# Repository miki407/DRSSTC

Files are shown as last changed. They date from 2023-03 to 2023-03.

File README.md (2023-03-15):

# Welcome
> **WARNING:**
> This project has not been tested yet. I cant guarantee that any of the circuits, PCBs, 3d models work or are accurate.

>This project is incomplete. The README isn't finished yet.

## Overview

This project is a tesla coil, DRSSTC to be more exact. Tesla coils are devices capable of generating extreme voltages that can be lethal if not operated correctly. 
> **Warning:** This project deals with high voltages. Replicate at your own risk.
 
 It is designed with a full bridge inverter connected to a MMC as the primary tank capacitor. This full bridge uses 4 parallel IGBT pairs driven by a single GDT. This GDT connects to the control circuit. Using a MIDI interrupter this coil has the ability to play music.

## Physical Design

The coil is designed with a skeleton topload and a vertical breakout point located in the middle of the topload. The primary coil is a pancake with a ground ring that is meant to protect it from flashover from topload.
>Note: The grounding ring is shouldn't be closed loop like shown in the image. This would short circuit the induced current and cause large current draw and energy loss.

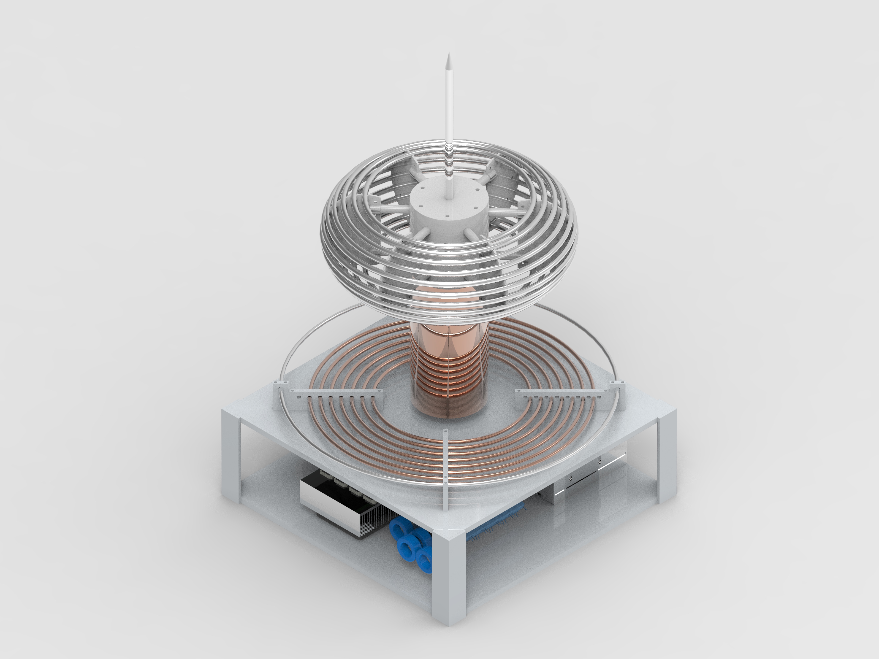
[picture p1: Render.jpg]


## Circuit
The circuit for the control circuit and inverter are inspired by the UD2.7c and EasyBridge made by [Loneoceans](https://www.loneoceans.com/labs/index.htm). These circuits have been modified to fit the needs of this project.
The interactive BOM of these boards are here:
[Inverter](https://htmlpreview.github.io/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)
[Control circuit](https://htmlpreview.github.io/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)

## Future additions

* Polyphonic MIDI interrupter
* Testing data
* Assembly guide
* Full BOM 

## Mistakes and Suggestions 
If I made any mistakes or if you want to suggest anything you can contact me on milosmilicevic575@gmail.com.

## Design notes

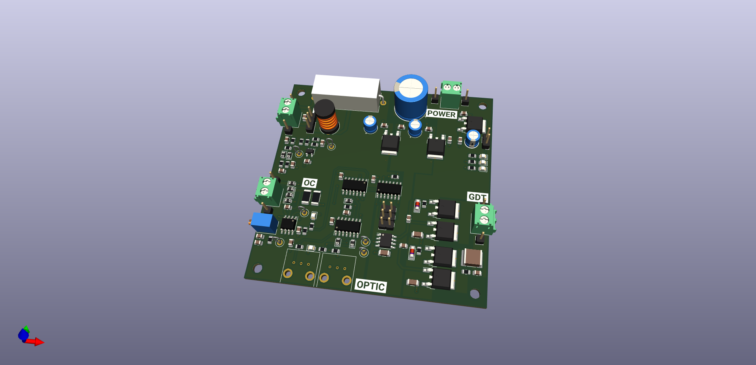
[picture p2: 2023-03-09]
DRSSTC controller.png

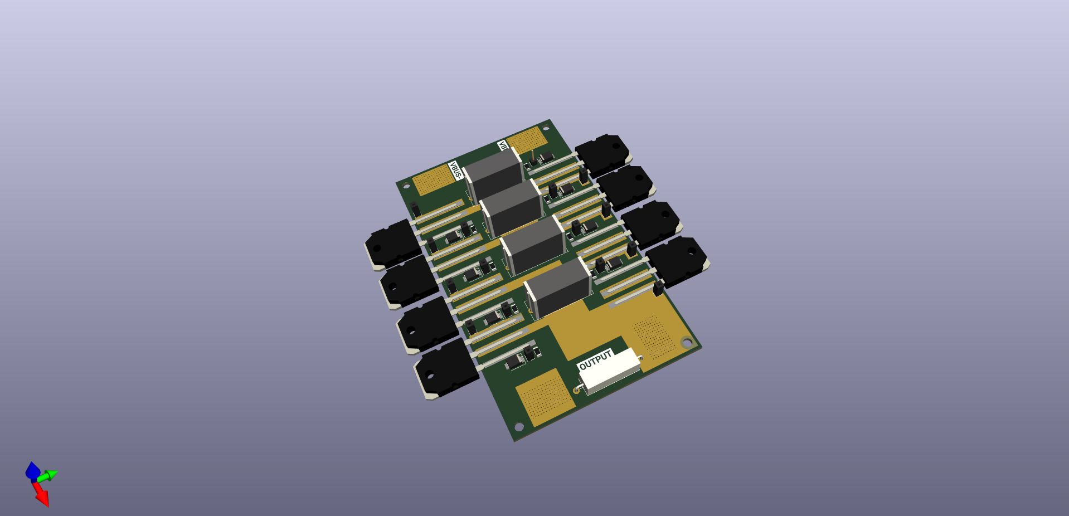
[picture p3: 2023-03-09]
Full Bridge.png

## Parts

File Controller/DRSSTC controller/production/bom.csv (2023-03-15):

Designator | Footprint | Quantity | Value | LCSC Part #
C201 | 1206 | 1 | 4.7u
C202 | 1206 | 1 | 4.7u
C203 | 1206 | 1 | 4.7u
C204 | 0805 | 1 | 1u
C205 | 0805 | 1 | 1u
C206 | 2220 | 1 | 2.2u
C207 | 0805 | 1 | 1u
C301 | 0805 | 1 | 100n
C302 | 0805 | 1 | 100n
C303 | 0805 | 1 | 100n
C304 | 0805 | 1 | 100n
C305 | 0805 | 1 | 100n
C306 | 0805 | 1 | 100n
C307 | 0805 | 1 | 100n
C308 | 0805 | 1 | 150p
C309 | 0805 | 1 | 150p
C310 | 0805 | 1 | 100n
C311 | 0805 | 1 | 100n
C312 | 0805 | 1 | 10n
C313 | 0805 | 1 | 1u
C314 | 0805 | 1 | 1n
C315 | 0805 | 1 | 10n
C401 | 0805 | 1 | 100n
C402 | 0805 | 1 | 100n
C403 | CP_Radial_D12.5mm_P5.00mm | 1 | 470u
C404 | 0805 | 1 | 100n
C405, C407, C410 | CP_Radial_D5.0mm_P2.50mm | 3 | 470u
C406 | 0805 | 1 | 100n
C408 | 0805 | 1 | 100n
C409 | 0805 | 1 | 100n
D201, D202 | D_MiniMELF | 2 | LL4148
D301 | 0805 | 1 | MBR0530
D302 | 0805 | 1 | MBR0530
D303 | 0805 | 1 | MBR0530
D304 | 0805 | 1 | MBR0530
D305 | 0805 | 1 | LL4148
D306 | 0805 | 1 | LL4148
D307 | 0805 | 1 | MBR0530
D308 | 0805 | 1 | MBR0530
D309 | 0805 | 1 | LED
D310 | 0805 | 1 | LED
D311 | 0805 | 1 | LL4148
D401 | 0805 | 1 | LED
D402 | 0805 | 1 | LED
D403 | 0805 | 1 | LED
H201, H202, H203, H204 | MountingHole_3.2mm_M3_Pad_Via | 4 | MountingHole_Pad
J201, J203, J301, J303, J304, J306, J401, J403 | PinHeader_1x01_P2.54mm_Vertical | 8 | Conn_01x01_Female
J202, J302, J305, J402 | TerminalBlock_Phoenix_PT-1,5-2-3.5-H_1x02_P3.50mm_Horizontal | 4 | Screw_Terminal_01x02
J307 | PinHeader_1x03_P2.54mm_Vertical | 1 | Conn_01x03_Male
J308, J309, J310, J404 | PinHeader_1x02_P2.54mm_Vertical | 4 | Conn_01x02_Male
L301 | L_Radial_D7.5mm_P5.00mm_Fastron_07P | 1 | L_Trim
Q201, Q203 | TO-252-2 | 2 | Q_PMOS_GDS
Q202, Q204 | TO-252-2 | 2 | Q_NMOS_GDS
R201 | 0805 | 1 | 1k
R202 | 0805 | 1 | 1k
R203 | 0805 | 1 | 15
R301 | 0805 | 1 | 1k
R302 | 0805 | 1 | 1k
R303 | 2010 | 1 | 5.1
R304 | 0805 | 1 | 1k
R305 | R_Axial_Power_L25.0mm_W9.0mm_P27.94mm | 1 | 51
R306 | 2010 | 1 | 5.1
R307 | 0805 | 1 | 100k
R308 | 0805 | 1 | 1k
R309 | 0805 | 1 | 1k
R310 | 0805 | 1 | 1k
R311 | 0805 | 1 | 1k
R312 | 0805 | 1 | 470
R313 | 0805 | 1 | 1k
R314 | 0805 | 1 | 470
R315 | 0805 | 1 | 470
R316 | 0805 | 1 | 470
R317 | 0805 | 1 | 470
R318 | 0805 | 1 | 100k
R319 | 0805 | 1 | 470
R401 | 0805 | 1 | 470
R402 | 0805 | 1 | 470
R403 | 0805 | 1 | 470
RV301 | Potentiometer_Bourns_3266Z_Horizontal | 1 | 10k
TP301, TP302, TP303, TP304, TP305, TP306 | TestPoint_Loop_D2.50mm_Drill1.0mm | 6 | TestPoint
U201 | SOIC-8_3.9x4.9mm_P1.27mm | 1 | UCC27524
U301, U302 | PLT135 | 2 | Optical_reciver
U303 | SO-14_3.9x8.65mm_P1.27mm | 1 | 74HC14
U304 | SO-8_3.9x4.9mm_P1.27mm | 1 | LM311
U305 | SO-14_3.9x8.65mm_P1.27mm | 1 | 74HC74
U306 | SO-14_3.9x8.65mm_P1.27mm | 1 | 74LS00
U307 | SOT-23-5 | 1 | TLV7031DBV
U401 | TO-252-2 | 1 | L7812
U402 | TO-252-2 | 1 | L7809
U403 | TO-252-2 | 1 | L7805

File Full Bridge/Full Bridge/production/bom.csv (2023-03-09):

Designator | Footprint | Quantity | Value | LCSC Part #
C1, C2, C3, C4 | C_Rect_L24.0mm_W8.6mm_P22.50mm_MKT | 4 | 1u
D1, D2, D3, D4, D5, D6, D7, D8 | D_SMB | 8 | D
H1, H2, H3, H4 | MountingHole_3.2mm_M3 | 4 | MountingHole
Q1, Q2, Q3, Q4, Q5, Q6, Q7, Q8 | To-3P-SideMount | 8 | Q_NMOS_GDS
R1 | 1206 | 1 | 5.1
R2 | 1206 | 1 | 5.1
R3 | 1206 | 1 | 5.1
R4 | 1206 | 1 | 5.1
R5 | 1206 | 1 | 5.1
R6 | 1206 | 1 | 5.1
R7 | 1206 | 1 | 5.1
R8 | 1206 | 1 | 5.1
R9 | R_Axial_Power_L20.0mm_W6.4mm_P25.40mm | 1 | 5.1k

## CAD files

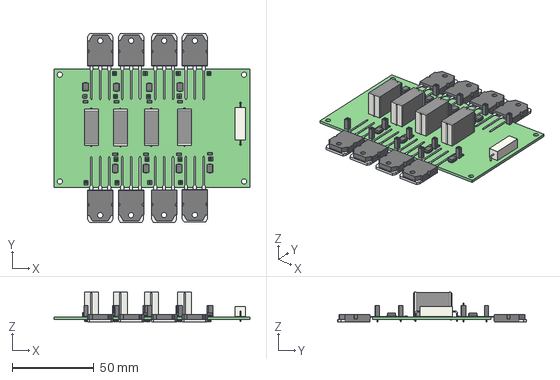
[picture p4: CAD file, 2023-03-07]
Full Bridge/Full Bridge/Full Bridge.step
120.1 x 116.0 x 18.1 mm
_autosave-Full Bridge PCB

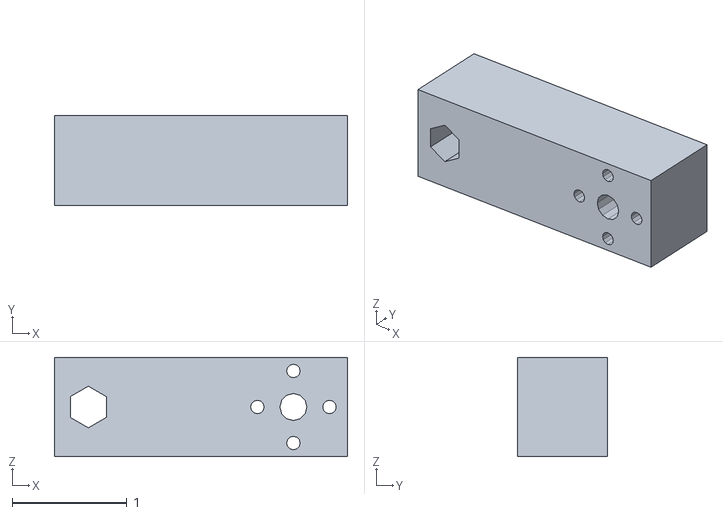
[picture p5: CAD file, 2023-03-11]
3D printing models/Gantry.stl
2.56 x 0.787 x 0.866

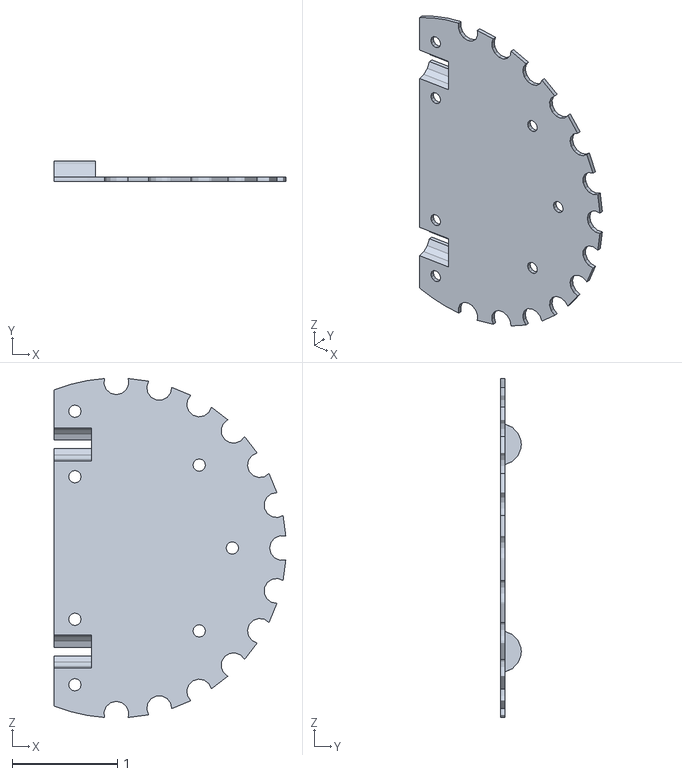
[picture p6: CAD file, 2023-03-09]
3D printing models/Topload Holder Half.stl
2.20 x 0.197 x 3.22

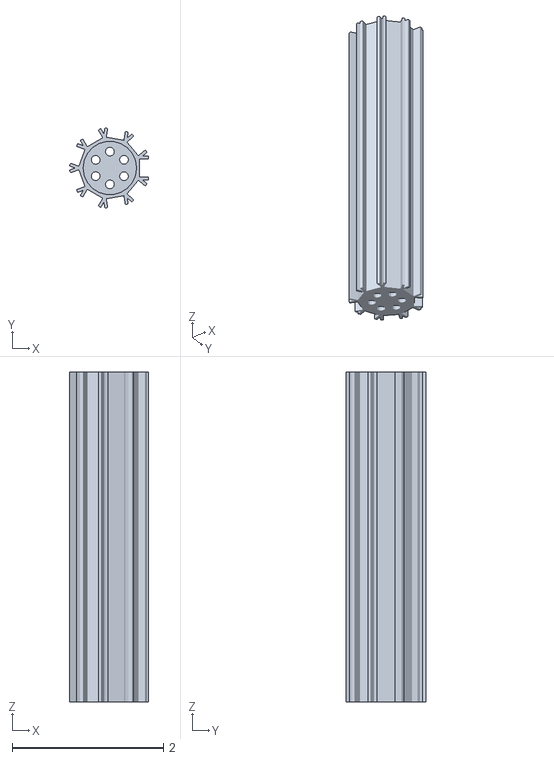
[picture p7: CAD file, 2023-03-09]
3D printing models/MMC_holder.stl
1.05 x 1.06 x 4.37

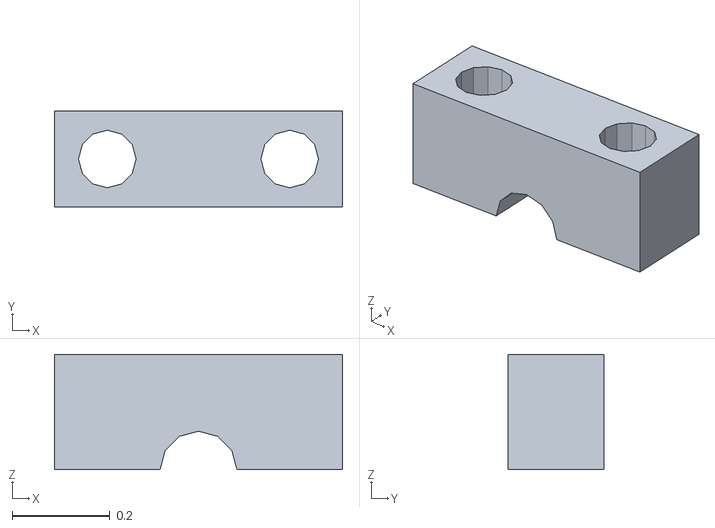
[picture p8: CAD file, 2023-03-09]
3D printing models/Primaty Holder_3.stl
0.591 x 0.197 x 0.236

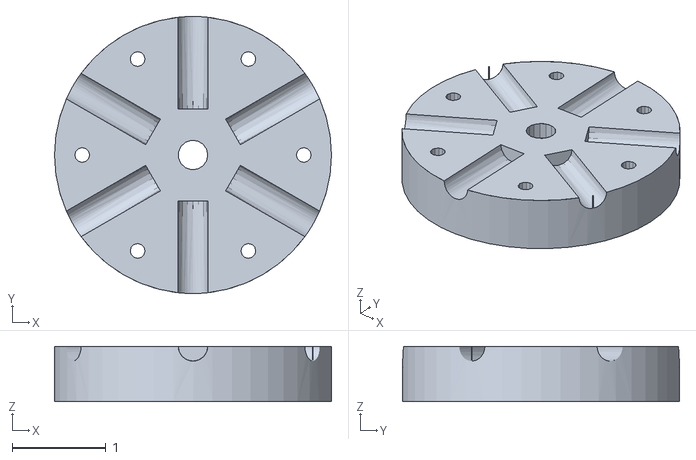
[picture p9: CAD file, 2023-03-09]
3D printing models/Topload Middle Half.stl
2.95 x 2.95 x 0.591

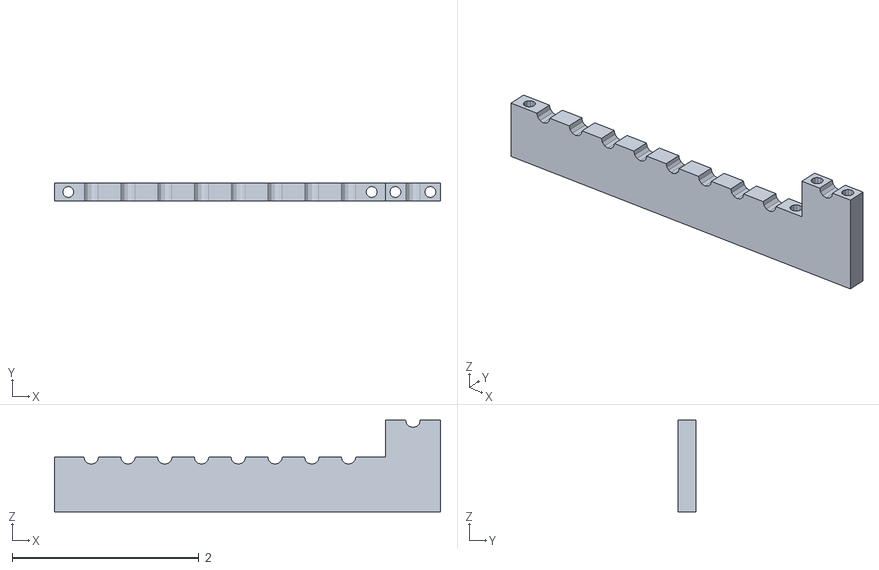
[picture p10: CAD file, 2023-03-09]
3D printing models/Primaty Holder.stl
4.13 x 0.197 x 0.984

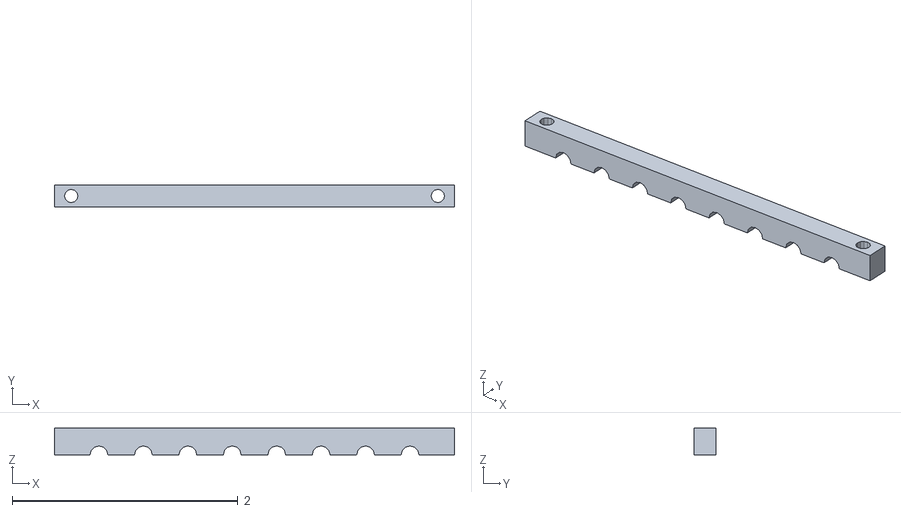
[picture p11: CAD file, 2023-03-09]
3D printing models/Primaty Holder_2.stl
3.54 x 0.197 x 0.236

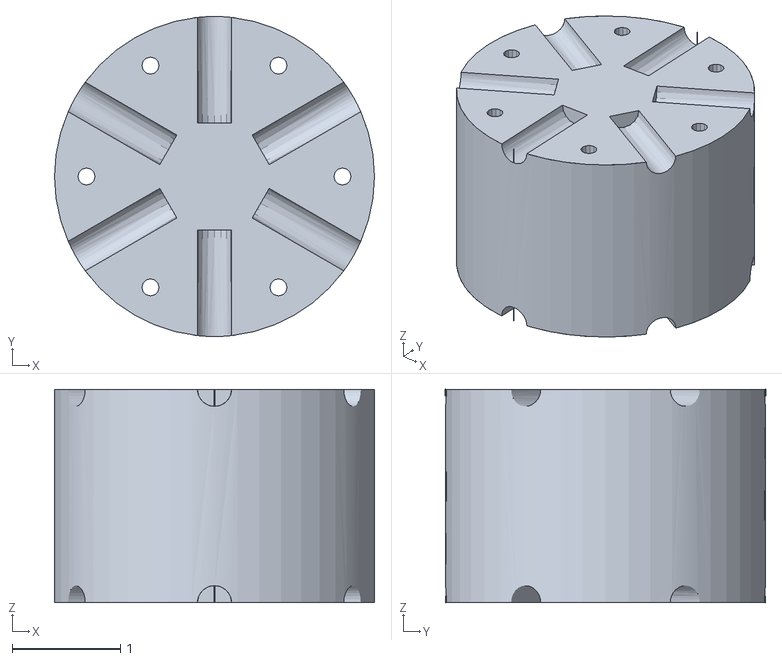
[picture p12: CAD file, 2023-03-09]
3D printing models/Topload Middle Half_2.stl
2.95 x 2.95 x 1.97

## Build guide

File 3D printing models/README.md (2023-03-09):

# 3D PRINTING
.STL files required for printing are located in this folder. The number of items that need be printed are as follows:
| File Name | Quantity | Filament Type | Approximate filament usage |
|---|---|---|---|
|`Topload Holder Half.stl`  | 12 | PLA | 60g total |
|`Topload Middle Half.stl`  | 2 | PLA | 54g total |
|`Topload Middle Half_2.stl`| 1 | PLA | 80g total |
|`Primary Holder.stl` | 4 | PLA | 28g total |
|`Primary Holder_2.stl` | 4 | PLA | 10g total |
|`Primary Holder_3.stl` | 4 | PLA | 2g total |
|`MMC Holder.stl` | 1 | PLA | 20g total |

> I sliced these files on 0.2mm layer height and printed them on a Prusa i3 MK3S
> 
>**Note:** If you plan to use or store the tesla coil in the sun for and extended period of time you should use UV resistant plastic filament.
## Assembly
**Coming soon**

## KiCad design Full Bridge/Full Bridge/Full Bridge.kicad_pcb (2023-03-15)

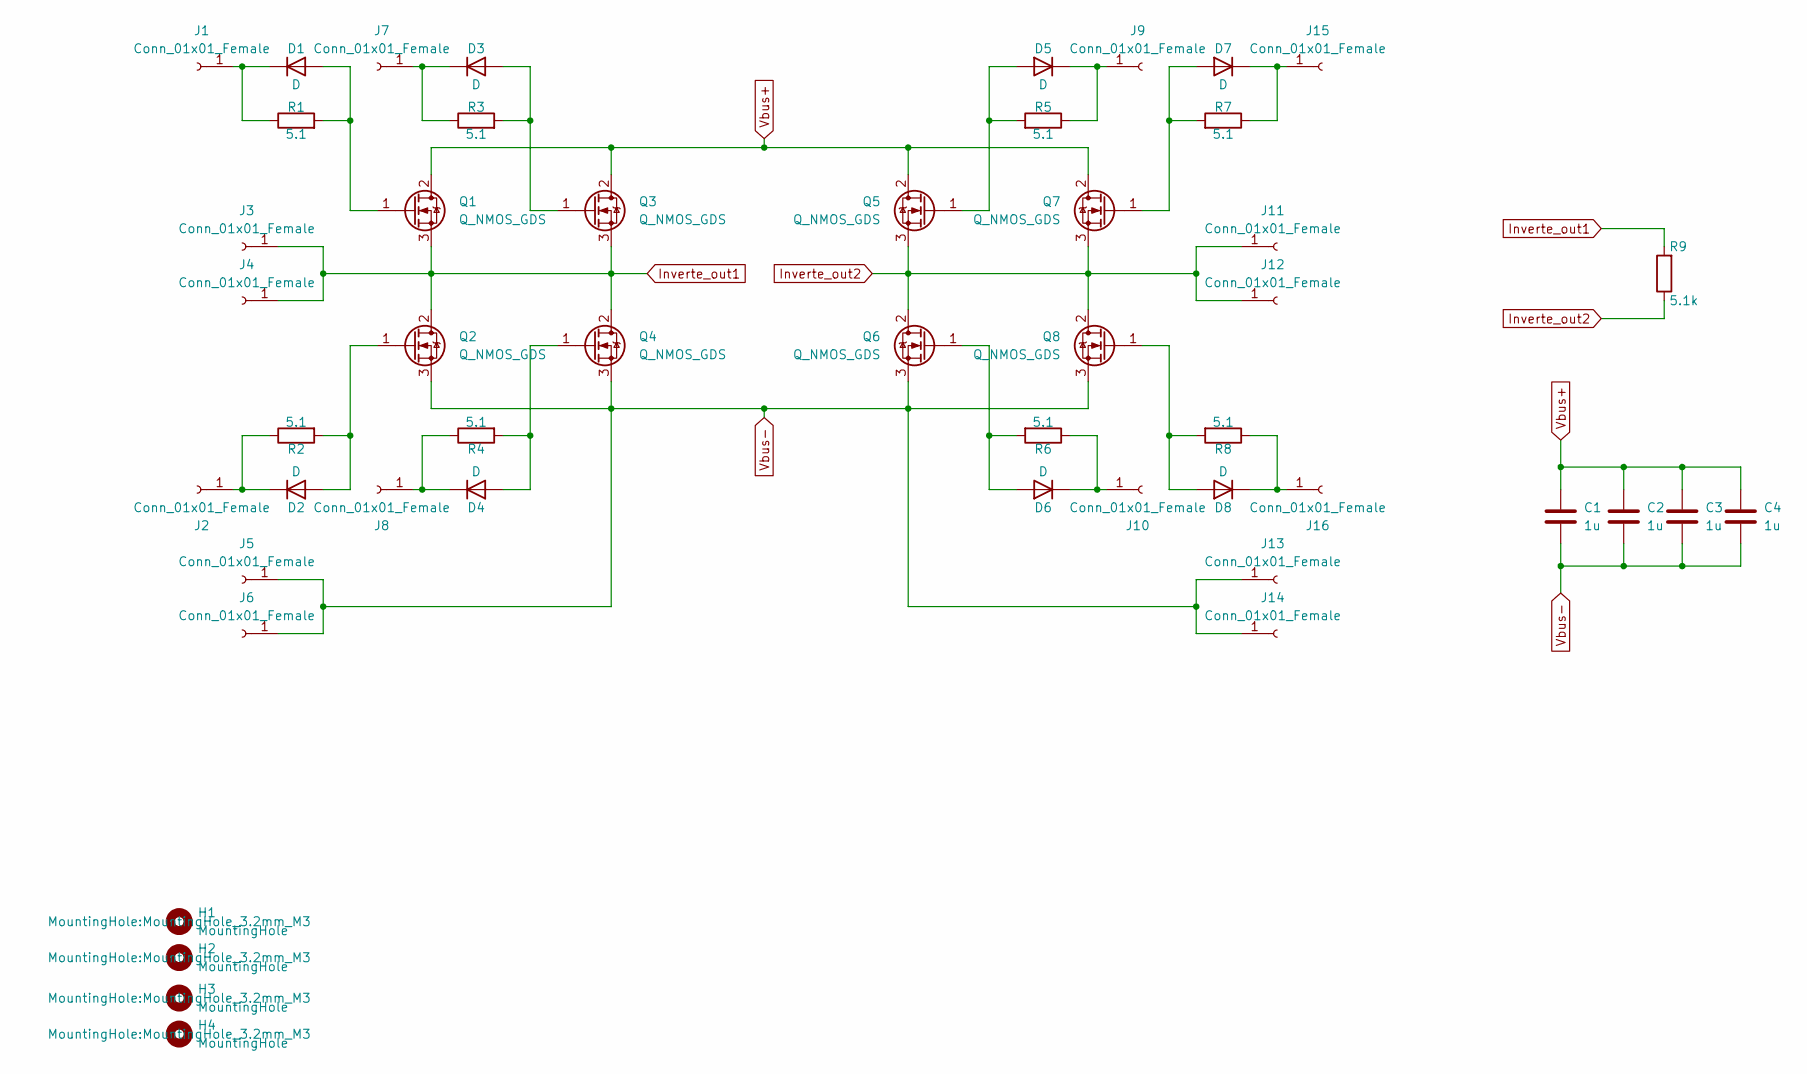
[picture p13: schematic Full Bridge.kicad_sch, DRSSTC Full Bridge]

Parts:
C1, C2, C3, C4: 1u; C_Rect_L24.0mm_W8.6mm_P22.50mm_MKT
D1, D2, D3, D4, D5, D6, D7, D8: D; D_SMB
H1, H2, H3, H4: MountingHole; MountingHole_3.2mm_M3
J1: Conn_01x01_Female; PinHeader_1x01_P2.54mm_Vertical
J2, J3, J4, J5, J6, J7, J8, J9, J10, J11, J12, J13, J14, J15, J16: Conn_01x01_Female; PinSocket_1x01_P2.54mm_Vertical
Q1, Q2, Q3, Q4, Q5, Q6, Q7, Q8: Q_NMOS_GDS; To-3P-SideMount
R1, R2, R3, R4, R5, R6, R7, R8: 5.1; R_1206_3216Metric
R9: 5.1k; R_Axial_Power_L20.0mm_W6.4mm_P25.40mm

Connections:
Inverte_out1: J3.1, J4.1, Q1.3 (S), Q2.2 (D), Q3.3 (S), Q4.2 (D), R9.2
Inverte_out2: J11.1, J12.1, Q5.3 (S), Q6.2 (D), Q7.3 (S), Q8.2 (D), R9.1
unnamed: D1.1 (K), J1.1, R1.1
unnamed: D1.2 (A), Q1.1 (G), R1.2
unnamed: D2.1 (K), J2.1, R2.1
unnamed: D2.2 (A), Q2.1 (G), R2.2
unnamed: D3.1 (K), J7.1, R3.1
unnamed: D3.2 (A), Q3.1 (G), R3.2
unnamed: D4.1 (K), J8.1, R4.1
unnamed: D4.2 (A), Q4.1 (G), R4.2
unnamed: D5.1 (K), J9.1, R5.1
unnamed: D5.2 (A), Q5.1 (G), R5.2
unnamed: D6.1 (K), J10.1, R6.1
unnamed: D7.1 (K), J15.1, R7.1
unnamed: D7.2 (A), Q7.1 (G), R7.2
unnamed: D8.1 (K), J16.1, R8.1
unnamed: D8.2 (A), Q8.1 (G), R8.2
unnamed: D6.2 (A), Q6.1 (G), R6.2
Vbus+: C1.1, C2.1, C3.1, C4.1, Q1.2 (D), Q3.2 (D), Q5.2 (D), Q7.2 (D)
Vbus-: C1.2, C2.2, C3.2, C4.2, J5.1, J6.1, J13.1, J14.1, Q2.3 (S), Q4.3 (S), Q6.3 (S), Q8.3 (S)

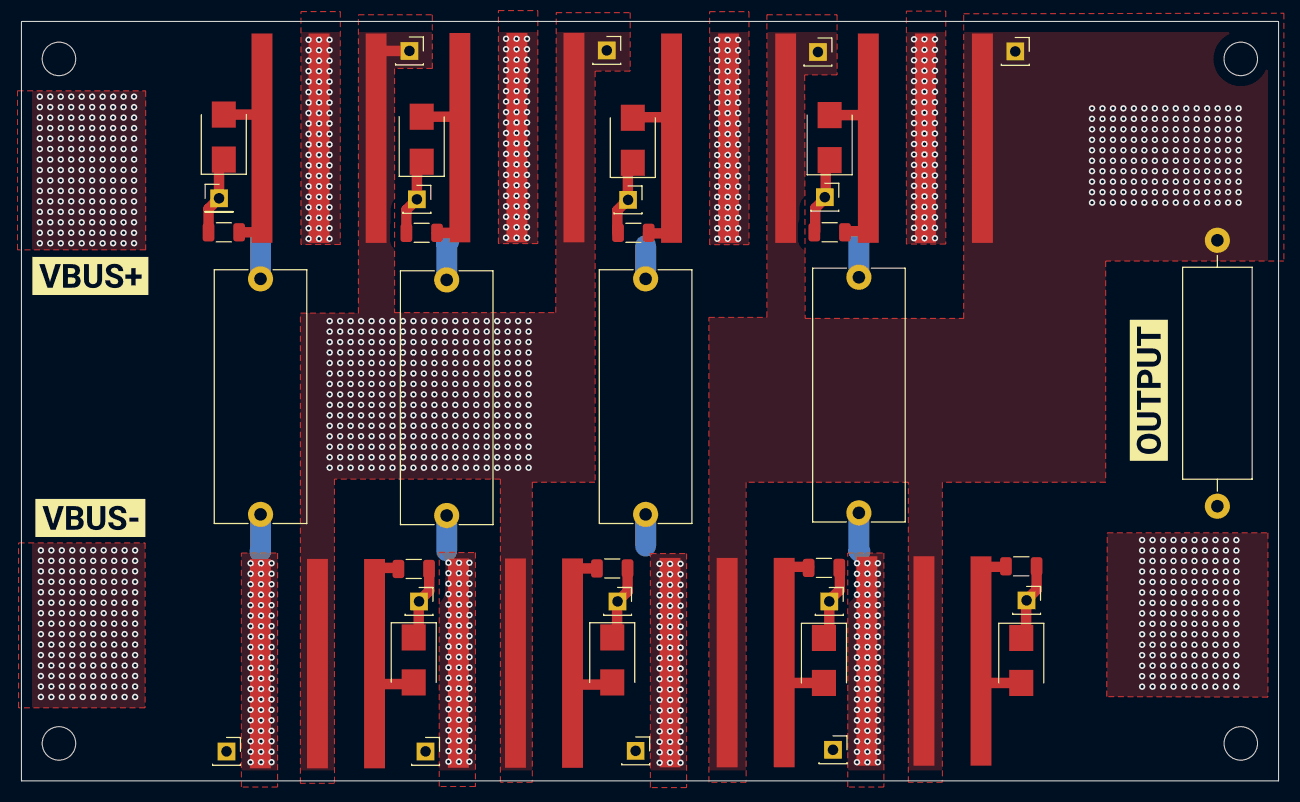
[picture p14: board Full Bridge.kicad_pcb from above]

Board: 2 copper layers, 120.1 x 72.5 mm, 52 parts (0 on the bottom side), 20 nets.

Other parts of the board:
kibuzzard-640732BF: G***; kibuzzard-640732BF
kibuzzard-640732D0: G***; kibuzzard-640732D0
kibuzzard-640732E7: G***; kibuzzard-640732E7

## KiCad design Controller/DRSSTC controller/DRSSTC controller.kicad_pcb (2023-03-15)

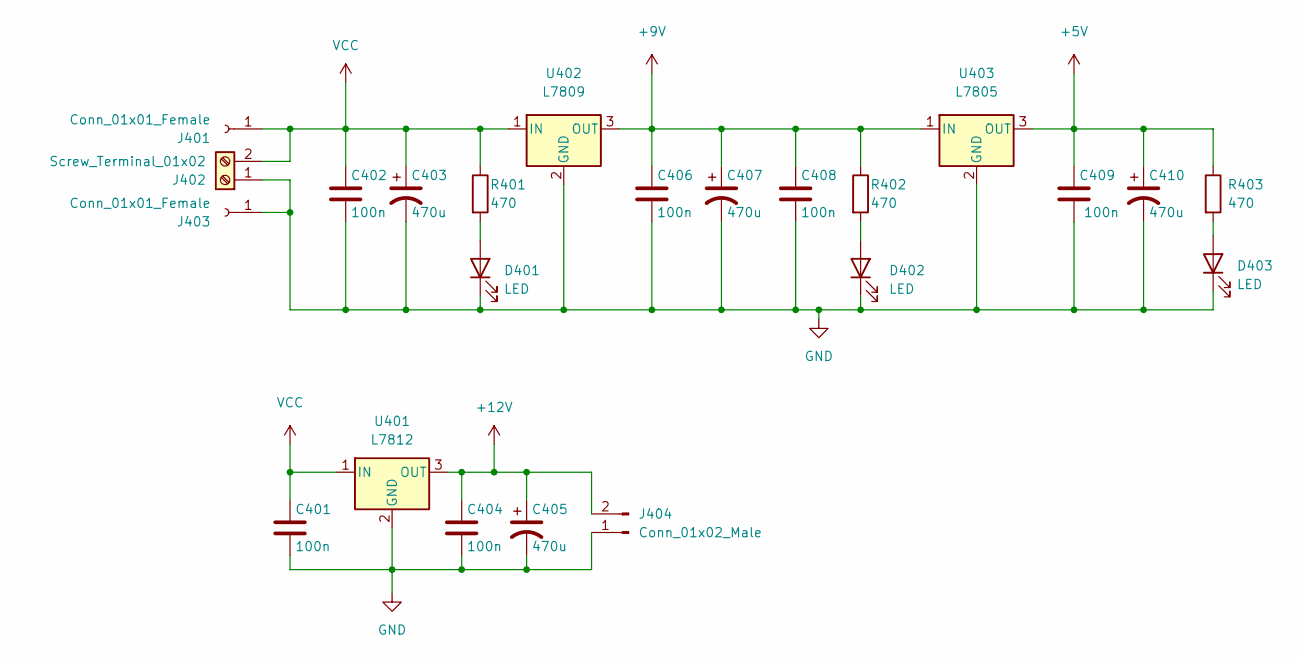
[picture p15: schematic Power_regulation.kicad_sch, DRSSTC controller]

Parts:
C401, C402, C404, C406, C408, C409: 100n; C_0805_2012Metric
C403: 470u; CP_Radial_D12.5mm_P5.00mm
C405, C407, C410: 470u; CP_Radial_D5.0mm_P2.50mm
D401, D402, D403: LED; LED_0805_2012Metric
J401, J403: Conn_01x01_Female; PinHeader_1x01_P2.54mm_Vertical
J402: Screw_Terminal_01x02; TerminalBlock_Phoenix_PT-1,5-2-3.5-H_1x02_P3.50mm_Horizontal
J404: Conn_01x02_Male; PinHeader_1x02_P2.54mm_Vertical
R401, R402, R403: 470; R_0805_2012Metric
U401: L7812; TO-252-2
U402: L7809; TO-252-2
U403: L7805; TO-252-2

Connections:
+5V: C409.1, C410.1, R403.1, U403.3 (OUT); also elsewhere on the board
+9V: C406.1, C407.1, C408.1, R402.1, U402.3 (OUT), U403.1 (IN); also elsewhere on the board
+12V: C404.1, C405.1, J404.2, U401.3 (OUT)
GND: C401.2, C402.2, C403.2, C404.2, C405.2, C406.2, C407.2, C408.2, C409.2, C410.2, D401.1 (K), D402.1 (K), D403.1 (K), J402.1, J403.1, J404.1, U401.2 (GND), U402.2 (GND), U403.2 (GND); also elsewhere on the board
unnamed: D401.2 (A), R401.2
unnamed: D402.2 (A), R402.2
unnamed: D403.2 (A), R403.2
VCC: C401.1, C402.1, C403.1, J401.1, J402.2, R401.1, U401.1 (IN), U402.1 (IN); also elsewhere on the board

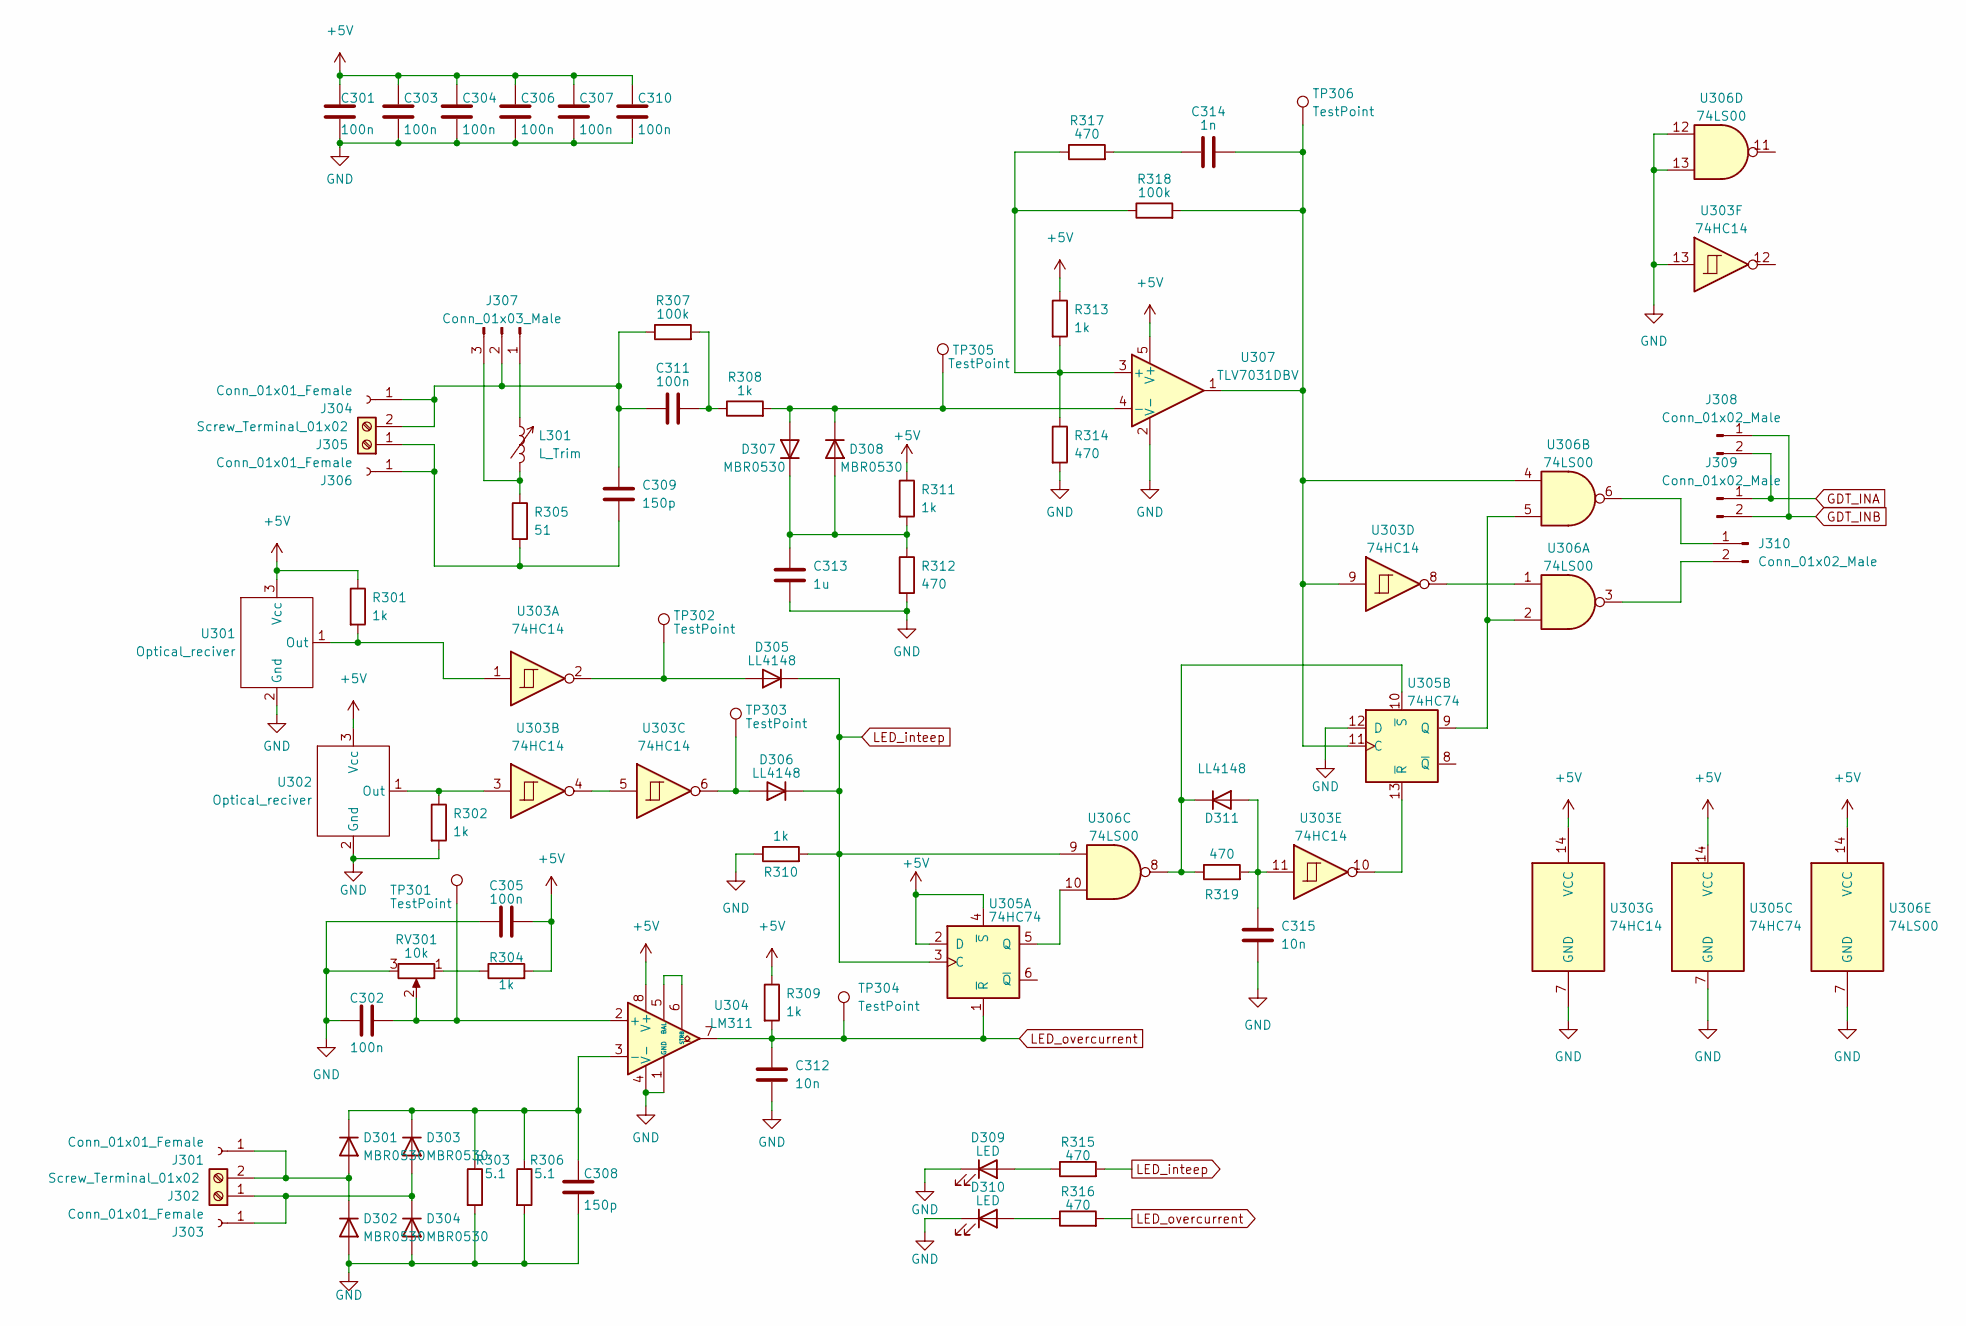
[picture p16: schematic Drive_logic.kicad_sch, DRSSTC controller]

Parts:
C301, C302, C303, C304, C305, C306, C307, C310, C311: 100n; C_0805_2012Metric
C308, C309: 150p; C_0805_2012Metric
C312, C315: 10n; C_0805_2012Metric
C313: 1u; C_0805_2012Metric
C314: 1n; C_0805_2012Metric
D301, D302, D303, D304, D307, D308: MBR0530; D_0805_2012Metric
D305, D306, D311: LL4148; D_0805_2012Metric
D309, D310: LED; LED_0805_2012Metric
J301, J303, J304, J306: Conn_01x01_Female; PinHeader_1x01_P2.54mm_Vertical
J302, J305: Screw_Terminal_01x02; TerminalBlock_Phoenix_PT-1,5-2-3.5-H_1x02_P3.50mm_Horizontal
J307: Conn_01x03_Male; PinHeader_1x03_P2.54mm_Vertical
J308, J309, J310: Conn_01x02_Male; PinHeader_1x02_P2.54mm_Vertical
L301: L_Trim; L_Radial_D7.5mm_P5.00mm_Fastron_07P
R301, R302, R304, R308, R309, R310, R311, R313: 1k; R_0805_2012Metric
R303, R306: 5.1; R_2010_5025Metric
R305: 51; R_Axial_Power_L25.0mm_W9.0mm_P27.94mm
R307, R318: 100k; R_0805_2012Metric
R312, R314, R315, R316, R317, R319: 470; R_0805_2012Metric
RV301: 10k; Potentiometer_Bourns_3266Z_Horizontal
TP301, TP302, TP303, TP304, TP305, TP306: TestPoint; TestPoint_Loop_D2.50mm_Drill1.0mm
U301, U302: Optical_reciver; PLT135
U303: 74HC14; SO-14_3.9x8.65mm_P1.27mm
U304: LM311; SO-8_3.9x4.9mm_P1.27mm
U305: 74HC74; SO-14_3.9x8.65mm_P1.27mm
U306: 74LS00; SO-14_3.9x8.65mm_P1.27mm
U307: TLV7031DBV; SOT-23-5

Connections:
+5V: C301.1, C303.1, C304.1, C305.2, C306.1, C307.1, C310.1, R301.1, R304.2, R309.1, R311.1, R313.1, U301.3 (Vcc), U302.3 (Vcc), U303.14 (VCC), U304.8 (V+), U305.2 (D), U305.4 (~S), U305.14 (VCC), U306.14 (VCC), U307.5 (V+); also elsewhere on the board
GDT_INA: J308.2, J309.1; also elsewhere on the board
GDT_INB: J308.1, J309.2; also elsewhere on the board
GND: C301.2, C302.1, C303.2, C304.2, C305.1, C306.2, C307.2, C308.2, C310.2, C312.2, C313.2, C315.2, D302.2 (A), D304.2 (A), D309.1 (K), D310.1 (K), R302.2, R303.2, R306.2, R310.1, R312.2, R314.2, RV301.3, U301.2 (Gnd), U302.2 (Gnd), U303.7 (GND), U303.13, U304.1 (GND), U304.4 (V-), U305.7 (GND), U305.12 (D), U306.7 (GND), U306.12, U306.13, U307.2 (V-); also elsewhere on the board
LED_inteep: D305.1 (K), D306.1 (K), R310.2, R315.2, U305.3 (C), U306.9
LED_overcurrent: C312.1, R309.2, R316.2, TP304.1, U304.7, U305.1 (~R)
unnamed: C311.2, R307.2, R308.1
unnamed: C314.1, R317.2
unnamed: D301.2 (A), D302.1 (K), J301.1, J302.2
unnamed: C308.1, D301.1 (K), D303.1 (K), R303.1, R306.1, U304.3 (-)
unnamed: D303.2 (A), D304.1 (K), J302.1, J303.1
unnamed: D305.2 (A), TP302.1, U303.2
unnamed: D306.2 (A), TP303.1, U303.6
unnamed: D307.2 (A), D308.1 (K), R308.2, TP305.1, U307.4 (-)
unnamed: C313.1, D307.1 (K), D308.2 (A), R311.2, R312.1
unnamed: D309.2 (A), R315.1
unnamed: D310.2 (A), R316.1
unnamed: C315.1, D311.2 (A), R319.2, U303.11
unnamed: D311.1 (K), R319.1, U305.10 (~S), U306.8
unnamed: C309.1, C311.1, J304.1, J305.2, J307.2, R307.1
unnamed: C309.2, J305.1, J306.1, R305.2
unnamed: J307.1, L301.1
unnamed: J307.3, L301.2, R305.1
unnamed: J310.1, U306.6
unnamed: J310.2, U306.3
unnamed: R304.1, RV301.1
unnamed: R301.2, U301.1 (Out), U303.1
unnamed: R302.1, U302.1 (Out), U303.3
unnamed: U303.4, U303.5
unnamed: U303.8, U306.1
unnamed: C302.2, RV301.2, TP301.1, U304.2 (+)
unnamed: U304.5 (BAL), U304.6 (STRB)
unnamed: U305.5 (Q), U306.10
unnamed: C314.2, R318.2, TP306.1, U303.9, U305.11 (C), U306.4, U307.1
unnamed: U305.9 (Q), U306.2, U306.5
unnamed: U303.10, U305.13 (~R)
unnamed: R313.2, R314.1, R317.1, R318.1, U307.3 (+)

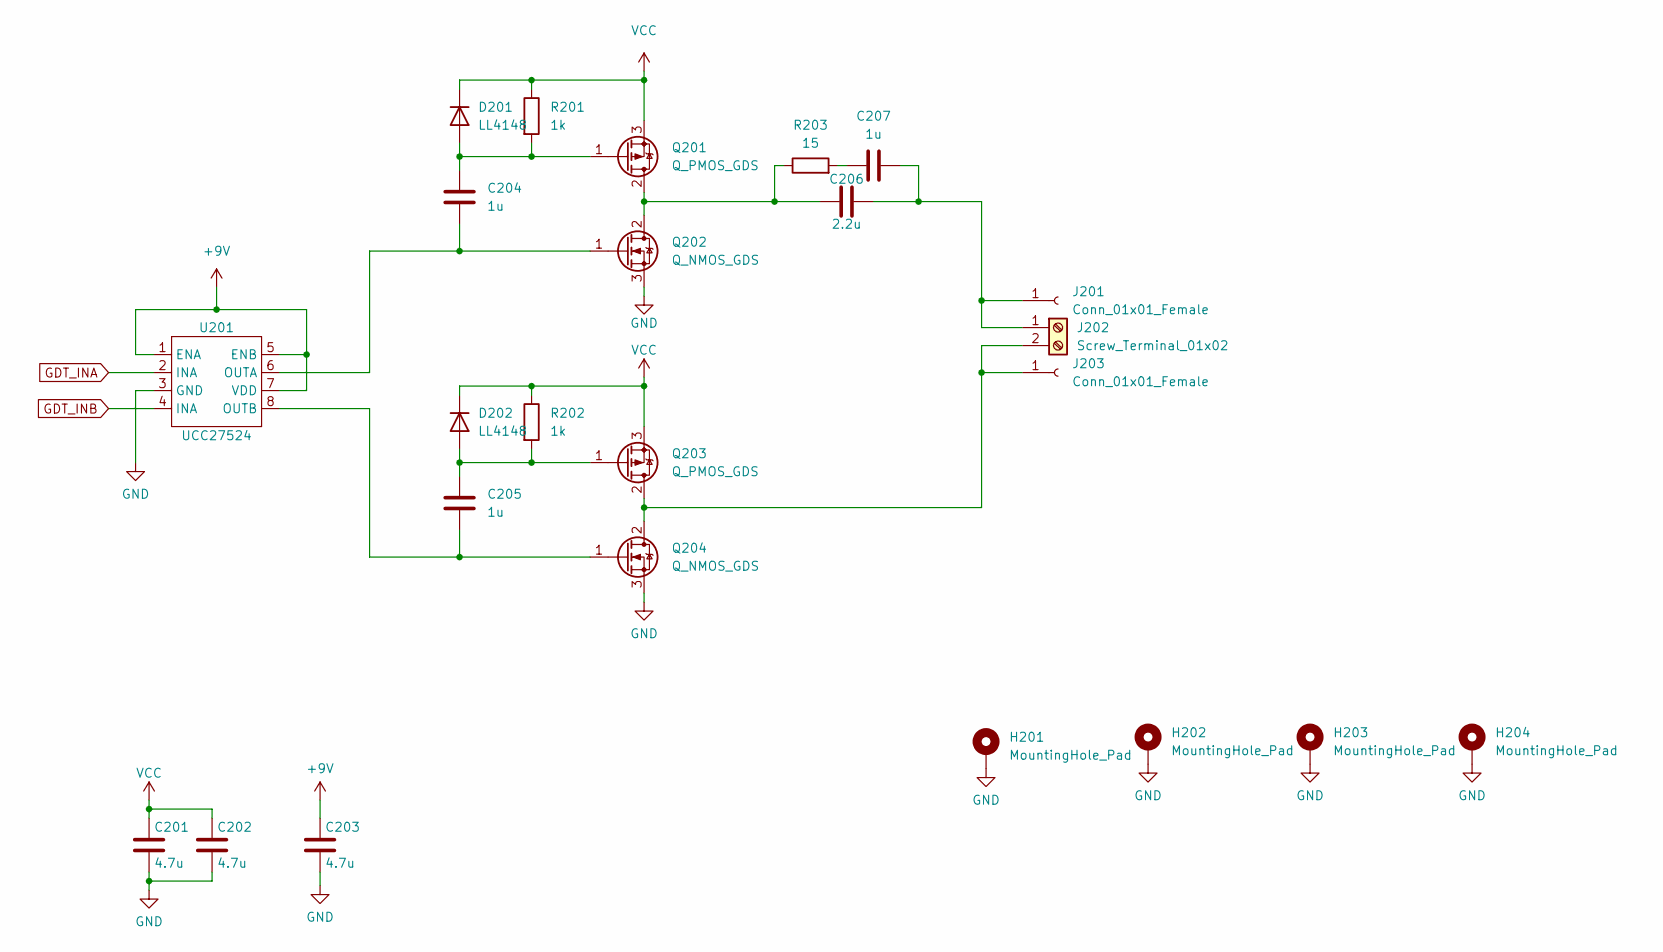
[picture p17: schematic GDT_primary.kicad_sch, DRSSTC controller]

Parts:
C201, C202, C203: 4.7u; C_1206_3216Metric
C204, C205, C207: 1u; C_0805_2012Metric
C206: 2.2u; C_2220_5650Metric
D201, D202: LL4148; D_MiniMELF
H201, H202, H203, H204: MountingHole_Pad; MountingHole_3.2mm_M3_Pad_Via
J201, J203: Conn_01x01_Female; PinHeader_1x01_P2.54mm_Vertical
J202: Screw_Terminal_01x02; TerminalBlock_Phoenix_PT-1,5-2-3.5-H_1x02_P3.50mm_Horizontal
Q201, Q203: Q_PMOS_GDS; TO-252-2
Q202, Q204: Q_NMOS_GDS; TO-252-2
R201, R202: 1k; R_0805_2012Metric
R203: 15; R_0805_2012Metric
U201: UCC27524; SOIC-8_3.9x4.9mm_P1.27mm

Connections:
+9V: C203.1, U201.1 (ENA), U201.5 (ENB), U201.7 (VDD); also elsewhere on the board
GDT_INA: U201.2 (INA); also elsewhere on the board
GDT_INB: U201.4 (INA); also elsewhere on the board
GND: C201.2, C202.2, C203.2, H201.1, H202.1, H203.1, H204.1, Q202.3 (S), Q204.3 (S), U201.3 (GND); also elsewhere on the board
unnamed: C207.1, R203.2
unnamed: C204.1, D201.2 (A), Q201.1 (G), R201.2
unnamed: C205.1, D202.2 (A), Q203.1 (G), R202.2
unnamed: C206.2, C207.2, J201.1, J202.1
unnamed: J202.2, J203.1, Q203.2 (D), Q204.2 (D)
unnamed: C206.1, Q201.2 (D), Q202.2 (D), R203.1
unnamed: C204.2, Q202.1 (G), U201.6 (OUTA)
unnamed: C205.2, Q204.1 (G), U201.8 (OUTB)
VCC: C201.1, C202.1, D201.1 (K), D202.1 (K), Q201.3 (S), Q203.3 (S), R201.1, R202.1; also elsewhere on the board

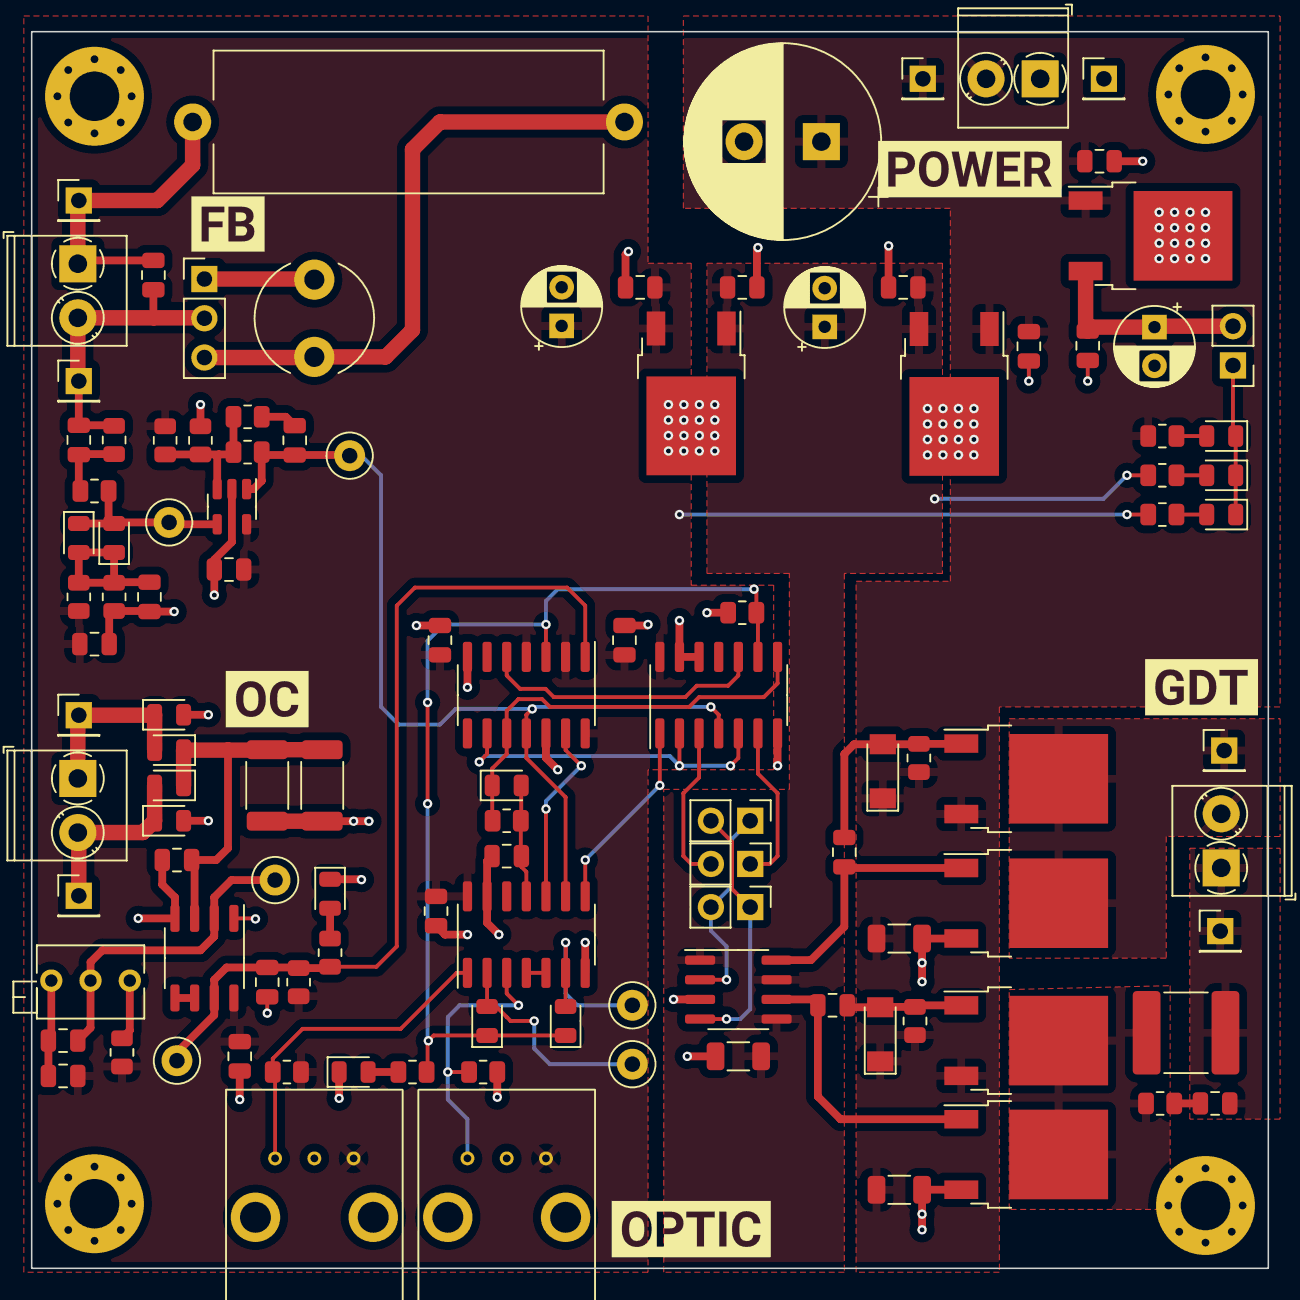
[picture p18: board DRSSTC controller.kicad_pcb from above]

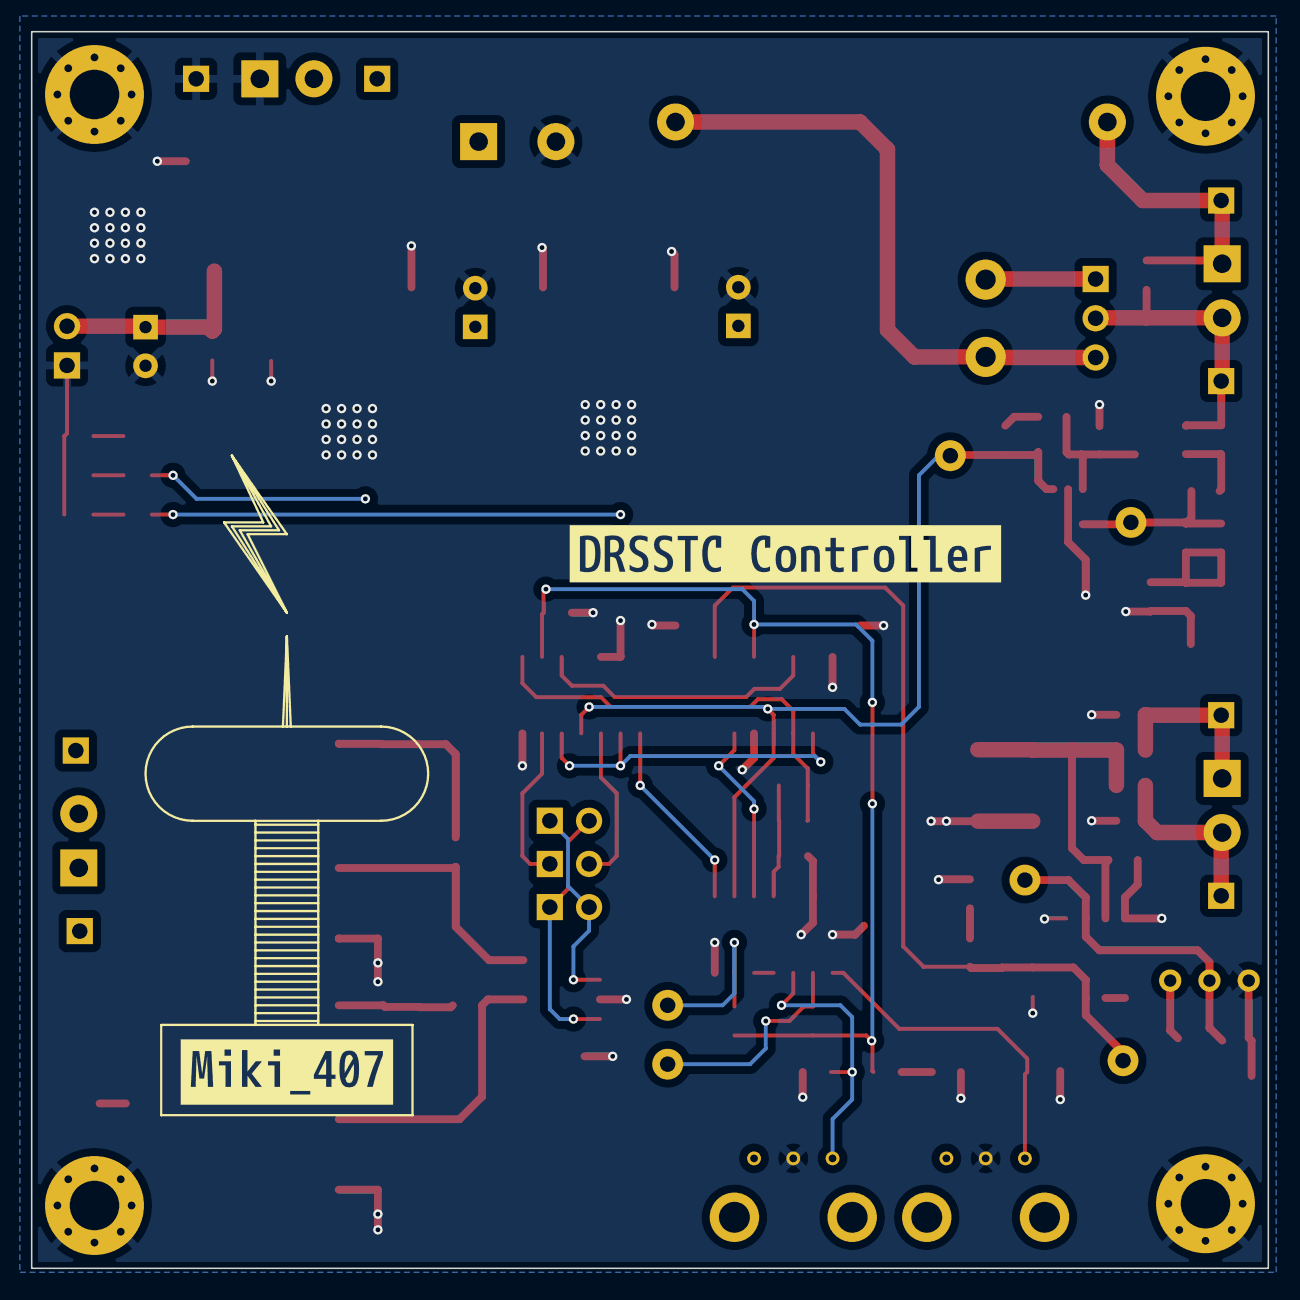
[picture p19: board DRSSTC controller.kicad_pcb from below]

Board: 2 copper layers, 80.0 x 80.0 mm, 124 parts (2 on the bottom side), 51 nets.

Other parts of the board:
kibuzzard-64072E6F: G***; kibuzzard-64072E6F
kibuzzard-64072E9F: G***; kibuzzard-64072E9F
kibuzzard-64072E65: G***; kibuzzard-64072E65
kibuzzard-64072E85: G***; kibuzzard-64072E85
kibuzzard-64072EC9: G***; kibuzzard-64072EC9
kibuzzard-64121B21: G***; kibuzzard-64121B21
kibuzzard-6412189F: G***; kibuzzard-6412189F

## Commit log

2023-03-01 0.1V control-circuit
    Next relese:
    Mounting holes;
    Fan header;
    Better layout;
    Bigger capacitors;
    [DRSSTC controller.kicad_pcb, DRSSTC controller.kicad_sch, DRSSTC.kicad_pcb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]
2023-03-09 V0.2c
    Added stl files
    PCB update
    [DRSSTC controller.kicad_pcb, DRSSTC controller.kicad_sch, Drive_logic.kicad_sch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]
2023-03-11 added 3d model
    [Gantry.stl]
2023-03-15 Updated circuit
    [DRSSTC controller.kicad_pcb, DRSSTC controller.kicad_sch, Drive_logic.kicad_sch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]
2023-03-15 Updated Production Files
    [DRSSTC controller.kicad_pcb, Full Bridge.kicad_pcb, bom.csv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]
